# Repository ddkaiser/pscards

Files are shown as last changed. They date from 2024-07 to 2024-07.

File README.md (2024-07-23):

# pscards
Custom cards for restoring or repairing Korg PS-3x00 polyphonic synthesizers

## Overview

### Goal
Korg Polyphonic Synthesizers (PS-3100, PS-3200, PS-3300) are complex and expensive synthesizers, but as these instruments are now at least 45 years old, occasionally their original parts fail, and there is a need for recreated parts, in order to keep the instrument in operating condition.

This project is to create spare circuit boards to keep these old synthesizers operating.

### Sub-Projects
- [`KLM-69`](KLM-69) : KiCad project
	-	KLM - 69 "GATE" board
		-	PS-3100 has KLM-69E
		-	PS-3200 has KLMC-69F or KLM-69G  (are these identical, unknown revision?)
- [`KLM-64`](KLM-64) : KiCad project
	-	KLM - 64 "SIGNAL GENERATOR" board
		-	PS-3100 has KLM-64E
		-	PS-3200 has KLMC-064D  (are these identical, unknown revision?)
- [`card-extender`](card-extender) : KiCad project
	-	Diagnostic support board
		-	A pass-through board that extends a card outside the Korg synth chassis, to enable easier access while diagnosing and repairing
		-	Plugs-in to Korg synth backplane, and provides 2 44-pin card socket connections to host the Korg KLM board.
		-	Sockets can be: [Sullins EBM22DREH](https://www.sullinscorp.com/product/?pn=EBM22DREH), [EDAC 305-044-520-202](https://edac.net/series/305?search_part=305-044-520-202), [Vector R644](https://www.vectorelect.com/connector-card-edge.html) or similar card sockets.
		-	Provides test-points in Molex 0.156” (3.96mm) header format, using vertical headers, [Molex KK396 part #0026481240](https://www.molex.com/en-us/products/part-detail/26481240)
- [`klib`](klib) : “KiCad Libraries” folder
	-	KiCad shared libraries (symbols, footprints, images, drawing sheets, project templates, 3D models) to be used common across sub-projects
	-	Shared folder should be referenced in sub-projects as `${KIPRJMOD}/../klib/`

## Criteria

### Technical Requirements
Original boards are:
- single-sided:
  - top layer has silk-screen component labels but no traces or soldermask
  - bottom layer of board has copper traces and soldermask
- 1.6mm thickness PCB
- 1oz. copper plating
	
#### Dimensions
- Dimensioning of card assumes landscape orientation
- Height: 177mm  (including edge-connector).
- Width: 240mm
- Edge connector pads mirror card-edge traces, but there can be some variance in edge connector sizing & placing
	- Edge connectors can be between 87.5mm & 89mm in width and 10mm in height.
	- Edge connectors can be from 14mm to 15.5mm from outer (left/right) card edge.
	- Edge connectors can have a 32.5mm to 34mm gap between them.

### Design Requirements
- Circuit projects require KiCad 8.0+
- Schematics pages are A4-sized
- Dimensioning in millimeters (mm)

## Notes

### External Resources
- Korg PS-3100 Schematic PDF document was retrieved from: https://archive.org/details/synthmanual-korg-ps-3100-schematics/

### Original Work is by Korg
- All references to the word Korg, pcb names and numbers, (KLM*) or use of Korg component references or other design, are based on the original work by Korg.
- This work in this project is to repair and restore an original Korg synthesizer, based on its service documents and schematics.

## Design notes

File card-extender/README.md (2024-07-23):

# pscards/card-extender

## Overview
KiCad project for creating a extender card. The extender card is useful for working on a Korg PS-Series Polyphonic Synthesizer.

The card is a pass-through board that extends a card outside the Korg synth chassis, to enable easier access while diagnosing and repairing

The extender card plugs-in to Korg synth backplane, and provides 2 44-pin card socket connections to host the Korg KLM board.

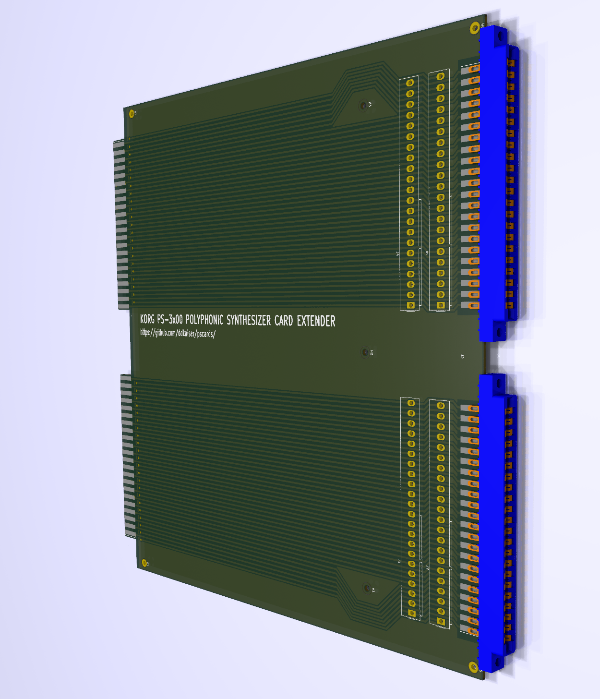
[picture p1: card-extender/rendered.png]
rendering of extender card for Korg PS-3x00 synths


## Parts

### Card-Edge Sockets
Sockets can be:

-	[Sullins EBM22DREH](https://www.sullinscorp.com/product/?pn=EBM22DREH)
-	[EDAC 305-044-520-202](https://edac.net/series/305?search_part=305-044-520-202)
-	[Vector R644](https://www.vectorelect.com/connector-card-edge.html)
-	or similar card sockets.

### Test Points
The card provides header pads for adding test points. 

The test points are:
-	Molex 0.156” (3.96mm) header format, using vertical headers
-	[Molex KK396 part #0026481240](https://www.molex.com/en-us/products/part-detail/26481240)

### Card Dimensions
- Dimensioning of card assumes landscape orientation
- Height: 228mm  (including edge-connector).
- Width: 240mm
- Edge connector pads mirror card-edge traces, but there can be some variance in edge connector sizing & placing
	- Edge connectors can be between 87.5mm & 89mm in width and 10mm in height.
	- Edge connectors can be from 14mm to 15.5mm from outer (left/right) card edge.
	- Edge connectors can have a 32.5mm to 34mm gap between them.

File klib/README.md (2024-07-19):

# pscards/klib
Directory for KiCad supporting libraries (symbols, footprints, images, sheet templates)

## Overview

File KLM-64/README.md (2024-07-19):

# pscards/KLM-64
KiCad project for creating restoration KLM-64 “SIGNAL GENERATOR” board for Korg PS-3x00 Polyphonic Synthesizers

## Overview

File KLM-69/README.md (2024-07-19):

# pscards/KLM-69
KiCad project for creating restoration KLM-69 “GATE” board for Korg PS-3x00 Polyphonic Synthesizers

## Overview

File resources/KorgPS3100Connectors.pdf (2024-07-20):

## Korg PS 3100

## Board Contacts

from front view | PS 3100
| KLM 64 | | KLM 64 | | KLM 69 | | KLM 69 | | KLM 69 | | KLM 69 | | KLM 62 | | KLM 63 | | KLM 76
Pin | Sig | | Sig | | Gate | | Gate | | Gate | | Gate | | Ctrl 1 | | Ctrl 2 | | Ctrl 3
44 | F (pitch) | 44 | B (pitch) | 44 | L Out | 44 | L Out | 44 | L Out | 44 | L Out | 44 | FC Mod R2 | 44 | MG1 FC Ctr | 44
43 | F# (pitch) | 43 | C (pitch) | 43 | U Out | 43 | U Out | 43 | U Out | 43 | U Out | 43 | FC Mod R1 | 43 | MG1 FC Ctr | 43
42 | G (pitch) | 42 | C# (pitch) | 42 | FC U | 42 | FC U | 42 | FC U | 42 | FC U | 42 | FC Mod 2 | 42 | MG1pNoise | 42
41 | G# (pitch) | 41 | D (pitch) | 41 | FC L | 41 | FC L | 41 | FC L | 41 | FC L | 41 | FC Mod 1 | 41 | MG1 wNoise | 41
40 | A (pitch) | 40 | D# (pitch) | 40 | Decay | 40 | Decay | 40 | Decay | 40 | Decay | 40 | FC Fine | 40 | | 40 | GND2
39 | A#(pitch) | 39 | E (pitch) | 39 | Ext.Attack | 39 | Ext.Attack | 39 | Ext.Attack | 39 | Ext.Attack | 39 | FC Coarse | 39 | | 39
38 | 4' | 38 | 4' | 38 | Attack | 38 | Attack | 38 | Attack | 38 | Attack | 38 | GND3 | 38 | GND3 | 38
37 | 8' | 37 | 8' | 37 | Expand | 37 | Expand | 37 | Expand | 37 | Expand | 37 | FC Bus Out | 37 | MG1 Tri | 37
36 | 16' | 36 | 16' | 36 | Sustain | 36 | Sustain | 36 | Sustain | 36 | Sustain | 36 | -15 V | 36 | MG1 Rect | 36
35 | | 35 | | 35 | Hold | 35 | Hold | 35 | Hold | 35 | Hold | 35 | GND2 | 35 | MG1 Saw dn | 35
34 | A#1 (Gate) | 34 | B1 (Gate) | 34 | E1 (sig) | 34 | E2 (sig) | 34 | E3 (sig) | 34 | E4 (sig) | 34 | L-Out (Mix) | 34 | MG1 Saw up | 34
33 | A#2 (Gate) | 33 | B2 (Gate) | 33 | D#1 (sig) | 33 | D#2 (sig) | 33 | D#3 (sig) | 33 | D#4 (sig) | 33 | GND2 | 33 | MG 1 ind | 33
32 | A#3 (Gate) | 32 | B3 (Gate) | 32 | D1 (sig) | 32 | D2 (sig) | 32 | D3 (sig) | 32 | D4 (sig) | 32 | L-In (Mix) | 32 | Ind 1 in | 32
31 | A#4 (Gate) | 31 | B4 (Gate) | 31 | C#1 (sig) | 31 | C#2 (sig) | 31 | C#3 (sig) | 31 | C#4 (sig) | 31 | GND2 | 31 | MG2 Sig Out | 31
30 | A1 (Gate) | 30 | C1 (Gate) | 30 | C1 (sig) | 30 | C2 (sig) | 30 | C3 (sig) | 30 | C4 (sig) | 30 | U-Out (Mix) | 30 | MG2 Sig In | 30
29 | A2 (Gate) | 29 | C2 (Gate) | 29 | B1 (sig) | 29 | B2 (sig) | 29 | B3 (sig) | 29 | B4 (sig) | 29 | GND2 | 29 | MG VCA Ctr. | 29
28 | A3 (Gate) | 28 | C3 (Gate) | 28 | A#1 (sig) | 28 | A#2 (sig) | 28 | A#3 (sig) | 28 | A#4 (sig) | 28 | U-In (Mix) | 28 | MG2 Ind | 28 | LMB 2
27 | A4 (Gate) | 27 | C4 (Gate) | 27 | A1 (sig) | 27 | A2 (sig) | 27 | A3 (sig) | 27 | A4 (sig) | 27 | GND2 | 27 | MG2 Out | 27 | LMA 2
26 | G#1 (Gate) | 26 | C#1 (Gate) | 26 | G#1 (sig) | 26 | G#2 (sig) | 26 | G#3 (sig) | 26 | G#4 (sig) | 26 | AM Sig Out | 26 | MG Freq. | 26 | Proc 2 out
25 | G#2 (Gate) | 25 | C#2 (Gate) | 25 | G1 (sig) | 25 | G2 (sig) | 25 | G3 (sig) | 25 | G4 (sig) | 25 | GND2 | 25 | | 25 | Proc 1 Out
24 | G#3 (Gate) | 24 | C#3 (Gate) | 24 | F#1 (sig) | 24 | F#2 (sig) | 24 | F#3 (sig) | 24 | F#4 (sig) | 24 | AM Sig in | 24 | | 24 | LMB 1
23 | G#4 (Gate) | 23 | C#4 (Gate) | 23 | F1 (sig) | 23 | F2 (sig) | 23 | F3 (sig) | 23 | F4 (sig) | 23 | AM Mod In | 23 | | 23 | LMA 1
22 | G1 (Gate) | 22 | D1 (Gate) | 22 | E1 (keyb) | 22 | E2 (keyb) | 22 | E3 (keyb) | 22 | E4 (keyb) | 22 | GND2 | 22 | GND2 | 22 | LM 1
21 | G2 (Gate) | 21 | D2 (Gate) | 21 | D#1 (keyb) | 21 | D#2 (keyb) | 21 | D#3 (keyb) | 21 | D#4 (keyb) | 21 | GND2 | 21 | | 21 | LM 2
20 | G3 (Gate) | 20 | D3 (Gate) | 20 | D1 (keyb) | 20 | D2 (keyb) | 20 | D3 (keyb) | 20 | D4 (keyb) | 20 | Res Out 2 | 20 | | 20 | VP 2 In
19 | G4 (Gate) | 19 | D4 (Gate) | 19 | C#1 (keyb) | 19 | C#2 (keyb) | 19 | C#3 (keyb) | 19 | C#4 (keyb) | 19 | GND2 | 19 | P50% Select | 19 | VP 1 In
18 | F#1 (Gate) | 18 | D#1 (Gate) | 18 | C1 (keyb) | 18 | C2 (keyb) | 18 | C3 (keyb) | 18 | C4 (keyb) | 18 | Res Out 1 | 18 | P30% Select | 18 | GEG Attack
17 | F#2 (Gate) | 17 | D#2 (Gate) | 17 | B1 (keyb) | 17 | B2 (keyb) | 17 | B3 (keyb) | 17 | B4 (keyb) | 17 | GND2 | 17 | P10% Select | 17 | GEG Out 0V
16 | F#3 (Gate) | 16 | D#3 (Gate) | 16 | A#1 (keyb) | 16 | A#2 (keyb) | 16 | A#3 (keyb) | 16 | A#4 (keyb) | 16 | Res In | 16 | PWM Select | 16 GEG Out +5V
15 | F#4 (Gate) | 15 | D#4 (Gate) | 15 | A1 (keyb) | 15 | A2 (keyb) | 15 | A3 (keyb) | 15 | A4 (keyb) | 15 | 15 | PWM In | 15GEG Auto Out
14 | F1 (Gate) | 14 | E1 (Gate) | 14 | G#1 (keyb) | 14 | G#2 (keyb) | 14 | G#3 (keyb) | 14 | G#4 (keyb) | 14 | 14 | Tri Select | 14 GEG Out -5V
13 | F2 (Gate) | 13 | E2 (Gate) | 13 | G1 (keyb) | 13 | G2 (keyb) | 13 | G3 (keyb) | 13 | G4 (keyb) | 13 | 13 | WFD (Sig) | 13 GEG Release
12 | F3 (Gate) | 12 | E3 (Gate) | 12 | F#1 (keyb) | 12 | F#2 (keyb) | 12 | F#3 (keyb) | 12 | F#4 (keyb) | 12 | | 12 | WFR (Sig) | 12 | GEG Auto In
11 | F4 (Gate) | 11 | E4 (Gate) | 11 | F1 (keyb) | 11 | F2 (keyb) | 11 | F3 (keyb) | 11 | F4 (keyb) | 11 | Peak Cont 3 | 11 | Saw Select | 11 | GEG Trig In
10 | | 10 | | 10 | nc / G2 (?) | 10 | nc / G2 (?) | 10 | nc / G2 (?) | 10 | nc / G2 (?) | 10 | Peak Cont 2 | 10 | FC L | 10 | GEG Delay
9 | | 9 | | 9 | (?) | 9 | (?) | 9 | (?) | 9 | (?) | 9 | Peak Cont 1 | 9 | FC U | 9 | Sync Ind
8 | | 8 | | 8 | Key Trig | 8 | Key Trig | 8 | Key Trig | 8 | Key Trig | 8 | Res Mod 2 | 8 | Balance | 8 | Sync In
7 | WFR | 7 | WFR | 7 | +10V | 7 | +10V | 7 | +10V | 7 | +10V | 7 | Res Mod 1 | 7 | VCF Mod 2 | 7 | S/H FC In
6 | WFD | 6 | WFD | 6 | Release | 6 | Release | 6 | Release | 6 | Release | 6 REL GND On | 6 | VCF Mod 1 | 6 | S/H In
5 | 5 | 5 | Peak | 5 | Peak | 5 | Peak | 5 | Peak | 5Gate REL Term | 5 | VCF FC | 5 | S/H Out
4 | | 4 | | 4 | GND3 | 4 | GND3 | 4 | GND3 | 4 | GND3 | 4 | HD GND On | 4 | FC Bias | 4 | Sync Out
3 | -15V | 3 | -15V | 3 | -15V | 3 | -15V | 3 | -15V | 3 | -15V | 3 | -15V | 3 | -15V | 3 | -15V
2 | GND | 2 | GND | 2 | GND | 2 | GND | 2 | GND | 2 | GND | 2 | GND | 2 | GND | 2 | GND
1 | +15V | 1 | +15V | 1 | +15V | 1 | +15V | 1 | +15V | 1 | +15V | 1 | +15V | 1 | +15V | 1 | +15V

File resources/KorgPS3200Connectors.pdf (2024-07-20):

## Korg PS 3200

## Board Contacts

from front view | PS 3200
| KLM 64 | | KLM 64 | | KLM 64 | | KLM 64 | | KLM 69 | | KLM 69 | | KLM 69 | | KLM 69 | | KLM 147 | | KLM 148 | | KLM 149 | | KLM 146 | | KLM 150 | | KLM 76
Pin | SG | | SG | | SG | | SG | | Gate | | Gate | | Gate | | Gate | | Freq.&Wave | | Filter & Rel. | | EQ AM BMix | | MG1, S/H, MB | | Ctrl 3 | | PHONE AMP
| | | | | | | | | | | | | | | | | Control | | Control | | | | MVCA | | MG2 AA, EBC | | VCA, GEG VP
44 | F (pitch) | 44 | B (pitch) | 44 | F (pitch) | 44 | B (pitch) | 44 | L Out | 44 | L Out | 44 | L Out | 44 | L Out | 44SG1 Temp. Bu | 44 | ? | 44 | P1 #18 | 44 | ? | 44 | SG2 16' | 44 | ?
43 | F# (pitch) | 43 | C (pitch) | 43 | F# (pitch) | 43 | C (pitch) | 43 | U Out | 43 | U Out | 43 | U Out | 43 | U Out | 43 | REV 1 | 43Ext Cutoff Freq | 43 | P0 #18 | 43 | ? | 43 | SG2 8' | 43 | ?
42 | G (pitch) | 42 | C# (pitch) | 42 | G (pitch) | 42 | C# (pitch) | 42 | FC U | 42 | FC U | 42 | FC U | 42 | FC U | 42 | GND 3 | 42 | MG1 | 42 | VS #18 | 42 | GND 3 | 42 | SG2 4' | 42 | ?
41 | G# (pitch) | 41 | D (pitch) | 41 | G# (pitch) | 41 | D (pitch) | 41 | FC L | 41 | FC L | 41 | FC L | 41 | FC L | 41 | MG1 | 41 | FC L | 41 | P1 #19 | 41 | MG1 Out | 41 | SG1 16' | 41 | ?
40 | A (pitch) | 40 | D# (pitch) | 40 | A (pitch) | 40 | D# (pitch) | 40 | Decay | 40 | Decay | 40 | Decay | 40 | Decay | 40SG2 Temp. Bu | 40 | FC U | 40 | P0 #19 | 40 MG1 Ext Freq | 40 | SG1 8' | 40 | GND2
39 | A#(pitch) | 39 | E (pitch) | 39 | A#(pitch) | 39 | E (pitch) | 39 | Ext.Attack | 39 | Ext.Attack | 39 | Ext.Attack | 39 | Ext.Attack | 39 SG2 Ext Mod | 39 | P1 #11 | 39 | VS #19 | 39 | ? | 39 | SG1 4' | 39 | ?
38 | 4' | 38 | 4' | 38 | 4' | 38 | 4' | 38 | Attack | 38 | Attack | 38 | Attack | 38 | Attack | 38 | MG 1 Check | 38 | P0 #11 | 38 | P1 #20 | 38 | ? | 38 | GND 3 | 38 | ?
37 | 8' | 37 | 8' | 37 | 8' | 37 | 8' | 37 | Expand | 37 | Expand | 37 | Expand | 37 | Expand | 37 | Tot Ext Mod | 37 | VS #11 | 37 | P0 #20 | 37 | ? | 37 | P1 #02 | 37 | ?
36 | 16' | 36 | 16' | 36 | 16' | 36 | 16' | 36 | Sustain | 36 | Sustain | 36 | Sustain | 36 | Sustain | 36 | Tot Freq | 36 | VS #13 | 36 | VS #20 | 36 | ? | 36SG1 Scale Ou | 36 | ?
35 | | 35 | | 35 | | 35 | | 35 | Hold | 35 | Hold | 35 | Hold | 35 | Hold | 35 | P1 #05 | 35 | P1 #13 | 35 | P1 #21 | 35 | ? | 35 | P0 #02 | 35 | ?
34 | A#1 (Gate) | 34 | B1 (Gate) | 34 | A#1 (Gate) | 34 | B1 (Gate) | 34 | E1 (sig) | 34 | E2 (sig) | 34 | E3 (sig) | 34 | E4 (sig) | 34 | P0 #08 | 34 | P0 #13 | 34 | P0 #21 | 34 | ? | 34 | VS #02 | 34 | ?
33 | A#2 (Gate) | 33 | B2 (Gate) | 33 | A#2 (Gate) | 33 | B2 (Gate) | 33 | D#1 (sig) | 33 | D#2 (sig) | 33 | D#3 (sig) | 33 | D#4 (sig) | 33 | ? | 33 | P1 #09 | 33 | VS #21 | 33 | P1 #28 | 33 | CVS #04 | 33 | ?
32 | A#3 (Gate) | 32 | B3 (Gate) | 32 | A#3 (Gate) | 32 | B3 (Gate) | 32 | D1 (sig) | 32 | D2 (sig) | 32 | D3 (sig) | 32 | D4 (sig) | 32 | VS #08 | 32 | P0 #09 | 32 | P1 #22 | 32 | P0 #28 | 32 | P1#04 | 32 | ?
31 | A#4 (Gate) | 31 | B4 (Gate) | 31 | A#4 (Gate) | 31 | B4 (Gate) | 31 | C#1 (sig) | 31 | C#2 (sig) | 31 | C#3 (sig) | 31 | C#4 (sig) | 31 | P1 #08 | 31 | VS #09 | 31 | P0 #22 | 31 | VS #28 | 31SG2 Scale Ou | 31 | ?
30 | A1 (Gate) | 30 | C1 (Gate) | 30 | A1 (Gate) | 30 | C1 (Gate) | 30 | C1 (sig) | 30 | C2 (sig) | 30 | C3 (sig) | 30 | C4 (sig) | 30 | P0 #05 | 30 | VS #12 | 30 | VS #22 | 30 | VS “27 | 30 | P0 #04 | 30 | ?
29 | A2 (Gate) | 29 | C2 (Gate) | 29 | A2 (Gate) | 29 | C2 (Gate) | 29 | B1 (sig) | 29 | B2 (sig) | 29 | B3 (sig) | 29 | B4 (sig) | 29 | VS #05 | 29 | P1 #12 | 29 | P1 #23 | 29 | P1 #27 | 29 | ? | 29 | ?
28 | A3 (Gate) | 28 | C3 (Gate) | 28 | A3 (Gate) | 28 | C3 (Gate) | 28 | A#1 (sig) | 28 | A#2 (sig) | 28 | A#3 (sig) | 28 | A#4 (sig) | 28 | REV 2 | 28 | Expand Cont | 28 | P0 #23 | 28 | P0 #27 | 28 | ? | 28 | LMB 2
27 | A4 (Gate) | 27 | C4 (Gate) | 27 | A4 (Gate) | 27 | C4 (Gate) | 27 | A1 (sig) | 27 | A2 (sig) | 27 | A3 (sig) | 27 | A4 (sig) | 27 | MG 3 Out | 27 | P0 #12 | 27 | VS #23 | 27 | P1 #29 | 27 | EC IN 2 | 27 | LMA 2
26 | G#1 (Gate) | 26 | C#1 (Gate) | 26 | G#1 (Gate) | 26 | C#1 (Gate) | 26 | G#1 (sig) | 26 | G#2 (sig) | 26 | G#3 (sig) | 26 | G#4 (sig) | 26 | P1 #07 | 26 | P1 #10 | 26 | P1 #24 | 26 | P0 #29 | 26 | GND | 26 | Proc 2 out
25 | G#2 (Gate) | 25 | C#2 (Gate) | 25 | G#2 (Gate) | 25 | C#2 (Gate) | 25 | G1 (sig) | 25 | G2 (sig) | 25 | G3 (sig) | 25 | G4 (sig) | 25 | P0 #06 | 25 | PEAK Cont | 25 | P0 #24 | 25 | VS #29 | 25 | EC IN 1 | 25 | Proc 1 Out
24 | G#3 (Gate) | 24 | C#3 (Gate) | 24 | G#3 (Gate) | 24 | C#3 (Gate) | 24 | F#1 (sig) | 24 | F#2 (sig) | 24 | F#3 (sig) | 24 | F#4 (sig) | 24 | ? | 24 | P0 #10 | 24 | VS #24 | 24 | ? | 24 | GND | 24 | LMB 1
23 | G#4 (Gate) | 23 | C#4 (Gate) | 23 | G#4 (Gate) | 23 | C#4 (Gate) | 23 | F1 (sig) | 23 | F2 (sig) | 23 | F3 (sig) | 23 | F4 (sig) | 23 | P/C (?) | 23 | P/C (?) | 23 | P/C (?) | 23 | P/C (?) | 23 | ? | 23 | LMA 1
22 | G1 (Gate) | 22 | D1 (Gate) | 22 | G1 (Gate) | 22 | D1 (Gate) | 22 | E1 (keyb) | 22 | E2 (keyb) | 22 | E3 (keyb) | 22 | E4 (keyb) | 22 | VS #06 | 22 | VS #10 | 22 | EQ out | 22 | VS #30 | 22 | GND 2 | 22 | LM 1
21 | G2 (Gate) | 21 | D2 (Gate) | 21 | G2 (Gate) | 21 | D2 (Gate) | 21 | D#1 (keyb) | 21 | D#2 (keyb) | 21 | D#3 (keyb) | 21 | D#4 (keyb) | 21 | P1 #06 | 21 | VS #16 | 21 | Direct Out | 21 | P1 #30 | 21 | EC Out | 21 | LM 2
20 | G3 (Gate) | 20 | D3 (Gate) | 20 | G3 (Gate) | 20 | D3 (Gate) | 20 | D1 (keyb) | 20 | D2 (keyb) | 20 | D3 (keyb) | 20 | D4 (keyb) | 20 | P0 #07 | 20 | P1 #16 | 20 | AM Check | 20 | P0 #30 | 20 | P1 #31 | 20 | VP 2 In
19 | G4 (Gate) | 19 | D4 (Gate) | 19 | G4 (Gate) | 19 | D4 (Gate) | 19 | C#1 (keyb) | 19 | C#2 (keyb) | 19 | C#3 (keyb) | 19 | C#4 (keyb) | 19 | VS #07 | 19 | Sustain Cont | 19 | Mix Out | 19 | GND 2 | 19 | P0 #31 | 19 | VP 1 In
18 | F#1 (Gate) | 18 | D#1 (Gate) | 18 | F#1 (Gate) | 18 | D#1 (Gate) | 18 | C1 (keyb) | 18 | C2 (keyb) | 18 | C3 (keyb) | 18 | C4 (keyb) | 18 | SG1 PWM | 18 | P0 #16 | 18 | GND 3 | 18 | ? | 18 | VS #31 | 18 | GEG Attack
17 | F#2 (Gate) | 17 | D#2 (Gate) | 17 | F#2 (Gate) | 17 | D#2 (Gate) | 17 | B1 (keyb) | 17 | B2 (keyb) | 17 | B3 (keyb) | 17 | B4 (keyb) | 17 | SG 1 WFR | 17 | Rel GND On | 17 | MG 1 (?) | 17 | SH Ind | 17 | VS #32 | 17 | GEG Out 0V
16 | F#3 (Gate) | 16 | D#3 (Gate) | 16 | F#3 (Gate) | 16 | D#3 (Gate) | 16 | A#1 (keyb) | 16 | A#2 (keyb) | 16 | A#3 (keyb) | 16 | A#4 (keyb) | 16 | SG 1 WFD | 16 | Rel Control | 16 | GND 2 | 16 | S/H Trig Out | 16 | P1 #32 | 16GEG Out +5V
15 | F#4 (Gate) | 15 | D#4 (Gate) | 15 | F#4 (Gate) | 15 | D#4 (Gate) | 15 | A1 (keyb) | 15 | A2 (keyb) | 15 | A3 (keyb) | 15 | A4 (keyb) | 15 | ? | 15 | VS #17 | 15 | AM Sig Out | 15 | ? | 15 | P0 #32 | 15GEG Auto Ou
14 | F1 (Gate) | 14 | E1 (Gate) | 14 | F1 (Gate) | 14 | E1 (Gate) | 14 | G#1 (keyb) | 14 | G#2 (keyb) | 14 | G#3 (keyb) | 14 | G#4 (keyb) | 14 | P1 #03 | 14 | P1 #17 | 14 | GND 2 | 14 | MG1 Ind | 14 | ADD IN 1 | 14 GEG Out -5V
13 | F2 (Gate) | 13 | E2 (Gate) | 13 | F2 (Gate) | 13 | E2 (Gate) | 13 | G1 (keyb) | 13 | G2 (keyb) | 13 | G3 (keyb) | 13 | G4 (keyb) | 13 | P0 #01 | 13 | P0 #17 | 13 | GND 2 | 13 | ? | 13 | ADD IN 2 | 13 GEG Release
12 | F3 (Gate) | 12 | E3 (Gate) | 12 | F3 (Gate) | 12 | E3 (Gate) | 12 | F#1 (keyb) | 12 | F#2 (keyb) | 12 | F#3 (keyb) | 12 | F#4 (keyb) | 12 | VS #01 | 12 | P1 #15 | 12 | Bmix Lo In | 12 | ? | 12 | INV Out | 12 | GEG Auto In
11 | F4 (Gate) | 11 | E4 (Gate) | 11 | F4 (Gate) | 11 | E4 (Gate) | 11 | F1 (keyb) | 11 | F2 (keyb) | 11 | F3 (keyb) | 11 | F4 (keyb) | 11 | P1 #01 | 11 | Decay Cont | 11 | GND | 11 | ? | 11 | ADD OUT | 11 | GEG Trig In
10 | | 10 | | 10 | | 10 | | 10 | nc / G2 (?) | 10 | nc / G2 (?) | 10 | nc / G2 (?) | 10 | nc / G2 (?) | 10 | P0 #03 | 10 | P0 #15 | 10 | BMix Up In | 10 | ? | 10 | PV Out | 10 | GEG Delay
9 | | 9 | | 9 | | 9 | | 9 | (?) | 9 | (?) | 9 | (?) | 9 | (?) | 9 | VS #03 | 9 | VS #15 | 9 | P1 #11 (?) | 9 | SH IN | 9 | MVCA Out | 9 | Sync Ind
8 | | 8 | | 8 | | 8 | | 8 | Key Trig | 8 | Key Trig | 8 | Key Trig | 8 | Key Trig | 8 | SG 2 PWM | 8 | VS #14 | 8 | P0 #11 (?) | 8 | S/H Trig In | 8 | MVCA IN | 8 | Sync In
7 | WFR | 7 | WFR | 7 | WFR | 7 | WFR | 7 | +10V | 7 | +10V | 7 | +10V | 7 | +10V | 7 | SG 2 WFR | 7 | P1 #14 | 7 | VS #11 (?) | 7 | SH Out | 7 | MVCA Ctrl | 7 | S/H FC In
6 | WFD | 6 | WFD | 6 | WFD | 6 | WFD | 6 | Release | 6 | Release | 6 | Release | 6 | Release | 6 | SG 2 WFD | 6 | Attack Cont | 6 | P1 #25 | 6 | Sync OUT | 6 | MG2 FC | 6 | S/H In
5 | | 5 | | 5 | | 5 | | 5 | Peak | 5 | Peak | 5 | Peak | 5 | Peak | 5 | ? | 5 | P0 #14 | 5 | P0 #25 | 5 | ? | 5 | MG2 Out | 5 | S/H Out
4 | 4 | 4 | 4 | 4 | GND3 | 4 | GND3 | 4 | GND3 | 4 | GND3 | 4 | ? | 4 | FC BIAS | 4 | VS #25 | 4MG1 Gain Ou | 4 | MG2 Ind | 4 | Sync Out
3 | -15V | 3 | -15V | 3 | -15V | 3 | -15V | 3 | -15V | 3 | -15V | 3 | -15V | 3 | -15V | 3 | -15V | 3 | -15V | 3 | -15V | 3 | -15V | 3 | -15V | 3 | -15V
2 | GND | 2 | GND | 2 | GND | 2 | GND | 2 | GND | 2 | GND | 2 | GND | 2 | GND | 2 | GND | 2 | GND | 2 | GND | 2 | GND | 2 | GND | 2 | GND
1 | +15V | 1 | +15V | 1 | +15V | 1 | +15V | 1 | +15V | 1 | +15V | 1 | +15V | 1 | +15V | 1 | +15V | 1 | +15V | 1 | +15V | 1 | +15V | 1 | +15V | 1 | +15V
GND2 nicht lesbar | AM MOD nicht lesbar

Programmer | Power | Programmer Selector | Abbreviaions | Knob Numbers
| KLM 151 | | KLM 152 | | KLM 153 | | KLM 65 | | KLM 154
| A/D DIS | | RAM AC | | Hold | | | | | A/D | Analog Digital Converter | #01 | SG1 Waveform
| DIS | | CG PC | | DOS D/A | | | | | AA | Adding Amp | #02 | SG1 Scale
44 | IA 5 | 44 | IA 5 | 44 | IA 5 | 44 | ? | 44 | ? | AC | Address Counter | #03 | SG2 Waveform
43 | IA 4 | 43 | IA 4 | 43 | IA 4 | 43 | ? | 43 | ? | AM | Amplitude Modulator | #04 | SG2 Scale
42 | IA 3 | 42 | IA 3 | 42 | IA 3 | 42 | ? | 42 | ? | BMix | Filter Balance Mixer | #05 | SG2 Frequency
41 | IA 2 | 41 | IA 2 | 41 | IA 2 | 41 | ? | 41 | ? | CG | Clock Generator | #06 | Total PWM Speed
40 | IA 1 | 40 | IA 1 | 40 | IA 1 | 40 | ? | 40 | ? | D/A | Digital Analog Converter | #07 | Total PWM Intensity
39 | ? | 39 | ? | 39 | ? | 39 | ? | 39 | ? | DIS | Data Input Scanner | #08 | Total Frequ Mod Intensity
38 | PI #32 | 38 | ? | 38 | P0 #32 | 38 | ? | 38 | ? | DOS | Data Output Scanner | #09 | DLPF Cutoff Freqency
37 | PI #31 | 37 | ? | 37 | P0 #31 | 37 | ? | 37 | ? | EBC | Ensemble Balance Control | #10 | DLPF Peak
36 | PI #30 | 36 | ? | 36 | P0 #30 | 36 | ? | 36 | PB 16 | EQ | Equalizer | #11 | DLPF KBD Filt Balance
35 | PI #29 | 35 | ? | 35 | P0 #29 | 35 | ? | 35 | PB 15 | GEG | General Envelope Generator | #12 | DLPF Expand
34 | PI #28 | 34 | ? | 34 | P0 #28 | 34 | ? | 34 | PB 14 | MB | Modulation Balance | #13 | DLPF Mod Intensity
33 | PI #27 | 33 | ? | 33 | P0 #27 | 33 | ? | 33 | PB 13 | MG | Modulation Generator | #14 | EM Attack Time
32 | PI #26 | 32 | ? | 32 | P0 #26 | 32 | ? | 32 | PB 12 | MVCA | Modulation VCA | #15 | EM Decay Time
31 | PI #25 | 31 | ? | 31 | P0 #25 | 31 | ? | 31 | PB 11 | PC | Programmer Control | #16 | EM Sustain Level
30 | PI #24 | 30 | ? | 30 | P0 #24 | 30 | ? | 30 | PB 10 | S/H | Sample & Hold | #17 | EM Release Time
29 | PI #23 | 29 | ? | 29 | P0 #23 | 29 | ? | 29 | PB 09 | SG | Signal Generator | #18 | EQ 8 kHz
28 | PI #22 | 28 | AD Start | 28 | P0 #22 | 28 | ? | 28 | PB 08 | VP | Voltage Processor | #19 | EQ 4 kHz
27 | PI #21 | 27 | Hold | 27 | P0 #21 | 27 | ? | 27 | PB 07 | PV | Preset Volume | #20 | EQ 2 kHz
26 | PI #20 | 26 | Data Latch | 26 | P0 #20 | 26 | ? | 26 | PB 06 | | | #21 | EQ 1kHz
25 | PI #19 | 25 | ? | 25 | P0 #19 | 25 | ? | 25 | PB 05 | | | #22 | EQ 500 Hz
24 | PI #18 | 24 | ? | 24 | P0 #18 | 24 | ? | 24 | PB 04 | | | #23 | EQ 250 Hz
23 | PI #17 | 23 | ? | 23 | P0 #17 | 23 | ? | 23 | PB 03 | | | #24 | EQ 125 Hz
| | | | | | | | | | | | #25 | Amplitude Modulation
22 | PI #16 | 22 | ? | 22 | P0 #16 | 22 | ? | 22 | PB 02 | | | #26 | KBD Vol Balance
21 | PI #15 | 21 | ? | 21 | P0 #15 | 21 | ? | 21 | PB 01 | | | #27 | MG1 Waveform
20 | PI #14 | 20 | ? | 20 | P0 #14 | 20 | ? | 20 | ? | | | #28 | MG1 Frequency
19 | PI #13 | 19 | ? | 19 | P0 #13 | 19 | ? | 19 | ? | | | #29 | S/H Clock
18 | PI #12 | 18 | ? | 18 | P0 #12 | 18 | ? | 18 | ? | | | #30 | Modulation Balance
17 | PI #11 | 17 | ? | 17 | P0 #11 | 17 | ? | 17 | ? | | | #31 | Ensemble
16 | PI #10 | 16 | ? | 16 | P0 #10 | 16 | ? | 16 | ? | | | #32 | Preset Volume
15 | PI #09 | 15 | ? | 15 | P0 #09 | 15 | ? | 15 | GNC
14 | PI #08 | 14 | ? | 14 | P0 #08 | 14 | ? | 14 | +15V
13 | PI #07 | 13 | ? | 13 | P0 #07 | 13 | ? | 13 | ?
12 | PI #06 | 12 | ? | 12 | P0 #06 | 12 | ? | 12 | WIRTE
11 | PI #05 | 11 | PS 2 | 11 | P0 #05 | 11 | TRAFO 4 | 11 | PA 4
10 | PI #04 | 10 | WRITE | 10 | P0 #04 | 10 | TRAFO 3 | 10 | PA 3
9 | PI #03 | 9 | CANCEL | 9 | P0 #03 | 9 | TRAFO 2 | 9 | PA 2
8 | PI #02 | 8 | RS 1 | 8 | P0 #02 | 8 | TRAFO 1 | 8 | PA 1
7 | PI #01 | 7 | ? | 7 | P0 #01 | 7 | VD +15V | 7 | PS 2
6 | PI #00 | 6 | ? | 6 | DATA Latch | 6 | +5V (?) | 6 | PS 1
5 | ? | 5 | ? | 5DA OUT CHCK | 5 | +10V | 5 | CANCEL 1
4 | ? | 4 | ? | 4 | ? | 4 | GND | 4 | CANCEL 2
3 | ? | 3 | -15V | 3 | -15V | 3 | -15V | 3 | P/C
2 | ? | 2 | GND | 2 | GND | 2 | GND | 2 | ?
1 | ? | 1 | +15V | 1 | +15V | 1 | +15V | 1 | ?

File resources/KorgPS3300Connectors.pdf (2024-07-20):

## Korg PS 3300

## Board Contacts

from front view | PS 3301 - 1 | PS 3301 - 2
| KLM 64 | | KLM 64 | | KLM 69 | | KLM 69 | | KLM 69 | | KLM 69 | | KLM 62 | | KLM 63 | | KLM 64 | | KLM 64 | | KLM 69 | | KLM 69 | | KLM 69
Pin | Sig | | Sig | | Gate | | Gate | | Gate | | Gate | | Ctrl 1 | | Ctrl 2 | | Sig | | Sig | | Gate | | Gate | | Gate
44 | F (pitch) | 44 | B (pitch) | 44 | L Out | 44 | L Out | 44 | L Out | 44 | L Out | 44 | FC Mod R2 | 44 | MG1 FC Ctr | 44 | F (pitch) | 44 | B (pitch) | 44 | L Out | 44 | L Out | 44 | L Out | 44
43 | F# (pitch) | 43 | C (pitch) | 43 | U Out | 43 | U Out | 43 | U Out | 43 | U Out | 43 | FC Mod R1 | 43 | MG1 FC Ctr | 43 | F# (pitch) | 43 | C (pitch) | 43 | U Out | 43 | U Out | 43 | U Out | 43
42 | G (pitch) | 42 | C# (pitch) | 42 | FC U | 42 | FC U | 42 | FC U | 42 | FC U | 42 | FC Mod 2 | 42 | MG1pNoise | 42 | G (pitch) | 42 | C# (pitch) | 42 | FC U | 42 | FC U | 42 | FC U | 42
41 | G# (pitch) | 41 | D (pitch) | 41 | FC L | 41 | FC L | 41 | FC L | 41 | FC L | 41 | FC Mod 1 | 41 | MG1 wNoise | 41 | G# (pitch) | 41 | D (pitch) | 41 | FC L | 41 | FC L | 41 | FC L | 41
40 | A (pitch) | 40 | D# (pitch) | 40 | Decay | 40 | Decay | 40 | Decay | 40 | Decay | 40 | FC Fine | 40 | | 40 | A (pitch) | 40 | D# (pitch) | 40 | Decay | 40 | Decay | 40 | Decay | 40
39 | A#(pitch) | 39 | E (pitch) | 39 | Ext.Attack | 39 | Ext.Attack | 39 | Ext.Attack | 39 | Ext.Attack | 39 | FC Coarse | 39 | | 39 | A#(pitch) | 39 | E (pitch) | 39 | Ext.Attack | 39 | Ext.Attack | 39 | Ext.Attack | 39
38 | 4' | 38 | 4' | 38 | Attack | 38 | Attack | 38 | Attack | 38 | Attack | 38 | GND3 | 38 | GND3 | 38 | 4' | 38 | 4' | 38 | Attack | 38 | Attack | 38 | Attack | 38
37 | 8' | 37 | 8' | 37 | Expand | 37 | Expand | 37 | Expand | 37 | Expand | 37 | FC Bus Out | 37 | MG1 Tri | 37 | 8' | 37 | 8' | 37 | Expand | 37 | Expand | 37 | Expand | 37
36 | 16' | 36 | 16' | 36 | Sustain | 36 | Sustain | 36 | Sustain | 36 | Sustain | 36 | -15 V | 36 | MG1 Rect | 36 | 16' | 36 | 16' | 36 | Sustain | 36 | Sustain | 36 | Sustain | 36
35 | | 35 | | 35 | Hold | 35 | Hold | 35 | Hold | 35 | Hold | 35 | GND2 | 35 | MG1 Saw dn | 35 | | 35 | | 35 | Hold | 35 | Hold | 35 | Hold | 35
34 | A#1 (Gate) | 34 | B1 (Gate) | 34 | E1 (sig) | 34 | E2 (sig) | 34 | E3 (sig) | 34 | E4 (sig) | 34 | L-Out (Mix) | 34 | MG1 Saw up | 34 | A#1 (Gate) | 34 | B1 (Gate) | 34 | E1 (sig) | 34 | E2 (sig) | 34 | E3 (sig) | 34
33 | A#2 (Gate) | 33 | B2 (Gate) | 33 | D#1 (sig) | 33 | D#2 (sig) | 33 | D#3 (sig) | 33 | D#4 (sig) | 33 | GND2 | 33 | MG 1 ind | 33 | A#2 (Gate) | 33 | B2 (Gate) | 33 | D#1 (sig) | 33 | D#2 (sig) | 33 | D#3 (sig) | 33
32 | A#3 (Gate) | 32 | B3 (Gate) | 32 | D1 (sig) | 32 | D2 (sig) | 32 | D3 (sig) | 32 | D4 (sig) | 32 | L-In (Mix) | 32 | Ind 1 in | 32 | A#3 (Gate) | 32 | B3 (Gate) | 32 | D1 (sig) | 32 | D2 (sig) | 32 | D3 (sig) | 32
31 | A#4 (Gate) | 31 | B4 (Gate) | 31 | C#1 (sig) | 31 | C#2 (sig) | 31 | C#3 (sig) | 31 | C#4 (sig) | 31 | GND2 | 31 | MG2 Sig Out | 31 | A#4 (Gate) | 31 | B4 (Gate) | 31 | C#1 (sig) | 31 | C#2 (sig) | 31 | C#3 (sig) | 31
30 | A1 (Gate) | 30 | C1 (Gate) | 30 | C1 (sig) | 30 | C2 (sig) | 30 | C3 (sig) | 30 | C4 (sig) | 30 | U-Out (Mix) | 30 | MG2 Sig In | 30 | A1 (Gate) | 30 | C1 (Gate) | 30 | C1 (sig) | 30 | C2 (sig) | 30 | C3 (sig) | 30
29 | A2 (Gate) | 29 | C2 (Gate) | 29 | B1 (sig) | 29 | B2 (sig) | 29 | B3 (sig) | 29 | B4 (sig) | 29 | GND2 | 29 | MG VCA Ctr. | 29 | A2 (Gate) | 29 | C2 (Gate) | 29 | B1 (sig) | 29 | B2 (sig) | 29 | B3 (sig) | 29
28 | A3 (Gate) | 28 | C3 (Gate) | 28 | A#1 (sig) | 28 | A#2 (sig) | 28 | A#3 (sig) | 28 | A#4 (sig) | 28 | U-In (Mix) | 28 | MG2 Ind | 28 | A3 (Gate) | 28 | C3 (Gate) | 28 | A#1 (sig) | 28 | A#2 (sig) | 28 | A#3 (sig) | 28
27 | A4 (Gate) | 27 | C4 (Gate) | 27 | A1 (sig) | 27 | A2 (sig) | 27 | A3 (sig) | 27 | A4 (sig) | 27 | GND2 | 27 | MG2 Out | 27 | A4 (Gate) | 27 | C4 (Gate) | 27 | A1 (sig) | 27 | A2 (sig) | 27 | A3 (sig) | 27
26 | G#1 (Gate) | 26 | C#1 (Gate) | 26 | G#1 (sig) | 26 | G#2 (sig) | 26 | G#3 (sig) | 26 | G#4 (sig) | 26 | AM Sig Out | 26 | MG Freq. | 26 | G#1 (Gate) | 26 | C#1 (Gate) | 26 | G#1 (sig) | 26 | G#2 (sig) | 26 | G#3 (sig) | 26
25 | G#2 (Gate) | 25 | C#2 (Gate) | 25 | G1 (sig) | 25 | G2 (sig) | 25 | G3 (sig) | 25 | G4 (sig) | 25 | GND2 | 25 | | 25 | G#2 (Gate) | 25 | C#2 (Gate) | 25 | G1 (sig) | 25 | G2 (sig) | 25 | G3 (sig) | 25
24 | G#3 (Gate) | 24 | C#3 (Gate) | 24 | F#1 (sig) | 24 | F#2 (sig) | 24 | F#3 (sig) | 24 | F#4 (sig) | 24 | AM Sig in | 24 | | 24 | G#3 (Gate) | 24 | C#3 (Gate) | 24 | F#1 (sig) | 24 | F#2 (sig) | 24 | F#3 (sig) | 24
23 | G#4 (Gate) | 23 | C#4 (Gate) | 23 | F1 (sig) | 23 | F2 (sig) | 23 | F3 (sig) | 23 | F4 (sig) | 23 | AM Mod In | 23 | | 23 | G#4 (Gate) | 23 | C#4 (Gate) | 23 | F1 (sig) | 23 | F2 (sig) | 23 | F3 (sig) | 23
22 | G1 (Gate) | 22 | D1 (Gate) | 22 | E1 (keyb) | 22 | E2 (keyb) | 22 | E3 (keyb) | 22 | E4 (keyb) | 22 | GND2 | 22 | GND2 | 22 | G1 (Gate) | 22 | D1 (Gate) | 22 | E1 (keyb) | 22 | E2 (keyb) | 22 | E3 (keyb) | 22
21 | G2 (Gate) | 21 | D2 (Gate) | 21 | D#1 (keyb) | 21 | D#2 (keyb) | 21 | D#3 (keyb) | 21 | D#4 (keyb) | 21 | GND2 | 21 | | 21 | G2 (Gate) | 21 | D2 (Gate) | 21 | D#1 (keyb) | 21 | D#2 (keyb) | 21 | D#3 (keyb) | 21
20 | G3 (Gate) | 20 | D3 (Gate) | 20 | D1 (keyb) | 20 | D2 (keyb) | 20 | D3 (keyb) | 20 | D4 (keyb) | 20 | Res Out 2 | 20 | | 20 | G3 (Gate) | 20 | D3 (Gate) | 20 | D1 (keyb) | 20 | D2 (keyb) | 20 | D3 (keyb) | 20
19 | G4 (Gate) | 19 | D4 (Gate) | 19 | C#1 (keyb) | 19 | C#2 (keyb) | 19 | C#3 (keyb) | 19 | C#4 (keyb) | 19 | GND2 | 19 | P50% Select | 19 | G4 (Gate) | 19 | D4 (Gate) | 19 | C#1 (keyb) | 19 | C#2 (keyb) | 19 | C#3 (keyb) | 19
18 | F#1 (Gate) | 18 | D#1 (Gate) | 18 | C1 (keyb) | 18 | C2 (keyb) | 18 | C3 (keyb) | 18 | C4 (keyb) | 18 | Res Out 1 | 18 | P30% Select | 18 | F#1 (Gate) | 18 | D#1 (Gate) | 18 | C1 (keyb) | 18 | C2 (keyb) | 18 | C3 (keyb) | 18
17 | F#2 (Gate) | 17 | D#2 (Gate) | 17 | B1 (keyb) | 17 | B2 (keyb) | 17 | B3 (keyb) | 17 | B4 (keyb) | 17 | GND2 | 17 | P10% Select | 17 | F#2 (Gate) | 17 | D#2 (Gate) | 17 | B1 (keyb) | 17 | B2 (keyb) | 17 | B3 (keyb) | 17
16 | F#3 (Gate) | 16 | D#3 (Gate) | 16 | A#1 (keyb) | 16 | A#2 (keyb) | 16 | A#3 (keyb) | 16 | A#4 (keyb) | 16 | Res In | 16 | PWM Select | 16 | F#3 (Gate) | 16 | D#3 (Gate) | 16 | A#1 (keyb) | 16 | A#2 (keyb) | 16 | A#3 (keyb) | 16
15 | F#4 (Gate) | 15 | D#4 (Gate) | 15 | A1 (keyb) | 15 | A2 (keyb) | 15 | A3 (keyb) | 15 | A4 (keyb) | 15 | | 15 | PWM In | 15 | F#4 (Gate) | 15 | D#4 (Gate) | 15 | A1 (keyb) | 15 | A2 (keyb) | 15 | A3 (keyb) | 15
14 | F1 (Gate) | 14 | E1 (Gate) | 14 | G#1 (keyb) | 14 | G#2 (keyb) | 14 | G#3 (keyb) | 14 | G#4 (keyb) | 14 | | 14 | Tri Select | 14 | F1 (Gate) | 14 | E1 (Gate) | 14 | G#1 (keyb) | 14 | G#2 (keyb) | 14 | G#3 (keyb) | 14
13 | F2 (Gate) | 13 | E2 (Gate) | 13 | G1 (keyb) | 13 | G2 (keyb) | 13 | G3 (keyb) | 13 | G4 (keyb) | 13 | | 13 | WFD (Sig) | 13 | F2 (Gate) | 13 | E2 (Gate) | 13 | G1 (keyb) | 13 | G2 (keyb) | 13 | G3 (keyb) | 13
12 | F3 (Gate) | 12 | E3 (Gate) | 12 | F#1 (keyb) | 12 | F#2 (keyb) | 12 | F#3 (keyb) | 12 | F#4 (keyb) | 12 | | 12 | WFR (Sig) | 12 | F3 (Gate) | 12 | E3 (Gate) | 12 | F#1 (keyb) | 12 | F#2 (keyb) | 12 | F#3 (keyb) | 12
11 | F4 (Gate) | 11 | E4 (Gate) | 11 | F1 (keyb) | 11 | F2 (keyb) | 11 | F3 (keyb) | 11 | F4 (keyb) | 11 | Peak Cont 3 | 11 | Saw Select | 11 | F4 (Gate) | 11 | E4 (Gate) | 11 | F1 (keyb) | 11 | F2 (keyb) | 11 | F3 (keyb) | 11
10 | | 10 | | 10 | nc / G2 (?) | 10 | nc / G2 (?) | 10 | nc / G2 (?) | 10 | nc / G2 (?) | 10 | Peak Cont 2 | 10 | FC L | 10 | | 10 | | 10 | nc / G2 (?) | 10 | nc / G2 (?) | 10 | nc / G2 (?) | 10
9 | | 9 | | 9 | (?) | 9 | (?) | 9 | (?) | 9 | (?) | 9 | Peak Cont 1 | 9 | FC U | 9 | | 9 | | 9 | (?) | 9 | (?) | 9 | (?) | 9
8 | | 8 | | 8 | Key Trig | 8 | Key Trig | 8 | Key Trig | 8 | Key Trig | 8 | Res Mod 2 | 8 | Balance | 8 | | 8 | | 8 | Key Trig | 8 | Key Trig | 8 | Key Trig | 8
7 | WFR | 7 | WFR | 7 | +10V | 7 | +10V | 7 | +10V | 7 | +10V | 7 | Res Mod 1 | 7 | VCF Mod 2 | 7 | WFR | 7 | WFR | 7 | +10V | 7 | +10V | 7 | +10V | 7
6 | WFD | 6 | WFD | 6 | Release | 6 | Release | 6 | Release | 6 | Release | 6 REL GND On | 6 | VCF Mod 1 | 6 | WFD | 6 | WFD | 6 | Release | 6 | Release | 6 | Release | 6
5 | 5 | 5 | Peak | 5 | Peak | 5 | Peak | 5 | Peak | 5Gate REL Term | 5 | VCF FC | 5 | 5 | 5 | Peak | 5 | Peak | 5 | Peak | 5
4 | | 4 | | 4 | GND3 | 4 | GND3 | 4 | GND3 | 4 | GND3 | 4 | HD GND On | 4 | FC Bias | 4 | | 4 | | 4 | GND3 | 4 | GND3 | 4 | GND3 | 4
3 | -15V | 3 | -15V | 3 | -15V | 3 | -15V | 3 | -15V | 3 | -15V | 3 | -15V | 3 | -15V | 3 | -15V | 3 | -15V | 3 | -15V | 3 | -15V | 3 | -15V | 3
2 | GND | 2 | GND | 2 | GND | 2 | GND | 2 | GND | 2 | GND | 2 | GND | 2 | GND | 2 | GND | 2 | GND | 2 | GND | 2 | GND | 2 | GND | 2
1 | +15V | 1 | +15V | 1 | +15V | 1 | +15V | 1 | +15V | 1 | +15V | 1 | +15V | 1 | +15V | 1 | +15V | 1 | +15V | 1 | +15V | 1 | +15V | 1 | +15V | 1

## Korg PS 3300

## Board Contacts

from front view | PS 3301 - 3 | PS 3302
KLM 69 | | KLM 62 | | KLM 63 | | KLM 64 | | KLM 64 | | KLM 69 | | KLM 69 | | KLM 69 | | KLM 69 | | KLM 62 | | KLM 63 | | KLM 76 | | KLM 77
Gate | | Ctrl 1 | | Ctrl 2 | | Sig | | Sig | | Gate | | Gate | | Gate | | Gate | | Ctrl 1 | | Ctrl 2 | | Ctrl 3 | | Mixer
L Out | 44 | FC Mod R2 | 44 | MG1 FC Ctr | 44 | F (pitch) | 44 | B (pitch) | 44 | L Out | 44 | L Out | 44 | L Out | 44 | L Out | 44 | FC Mod R2 | 44 | MG1 FC Ctr | 44 | | 44
U Out | 43 | FC Mod R1 | 43 | MG1 FC Ctr | 43 | F# (pitch) | 43 | C (pitch) | 43 | U Out | 43 | U Out | 43 | U Out | 43 | U Out | 43 | FC Mod R1 | 43 | MG1 FC Ctr | 43 | | 43
FC U | 42 | FC Mod 2 | 42 | MG1pNoise | 42 | G (pitch) | 42 | C# (pitch) | 42 | FC U | 42 | FC U | 42 | FC U | 42 | FC U | 42 | FC Mod 2 | 42 | MG1pNoise | 42 | 42 Ext Level Ctrl
FC L | 41 | FC Mod 1 | 41 | MG1 wNoise | 41 | G# (pitch) | 41 | D (pitch) | 41 | FC L | 41 | FC L | 41 | FC L | 41 | FC L | 41 | FC Mod 1 | 41 | MG1 wNoise | 41 | | 41 | Phone Out
Decay | 40 | FC Fine | 40 | | 40 | A (pitch) | 40 | D# (pitch) | 40 | Decay | 40 | Decay | 40 | Decay | 40 | Decay | 40 | FC Fine | 40 | | 40 | GND2 | 40 | Phone Level
Ext.Attack | 39 | FC Coarse | 39 | | 39 | A#(pitch) | 39 | E (pitch) | 39 | Ext.Attack | 39 | Ext.Attack | 39 | Ext.Attack | 39 | Ext.Attack | 39 | FC Coarse | 39 | | 39 | | 39
Attack | 38 | GND3 | 38 | GND3 | 38 | 4' | 38 | 4' | 38 | Attack | 38 | Attack | 38 | Attack | 38 | Attack | 38 | GND3 | 38 | GND3 | 38 | | 38
Expand | 37 | FC Bus Out | 37 | MG1 Tri | 37 | 8' | 37 | 8' | 37 | Expand | 37 | Expand | 37 | Expand | 37 | Expand | 37 | FC Bus Out | 37 | MG1 Tri | 37 | | 37 | Mix OUT ?
Sustain | 36 | -15 V | 36 | MG1 Rect | 36 | 16' | 36 | 16' | 36 | Sustain | 36 | Sustain | 36 | Sustain | 36 | Sustain | 36 | -15 V | 36 | MG1 Rect | 36 | | 36
Hold | 35 | GND2 | 35 | MG1 Saw dn | 35 | 35 | 35 | Hold | 35 | Hold | 35 | Hold | 35 | Hold | 35 | GND2 | 35 | MG1 Saw dn | 35 | 35 Mix Ch 3 In ?
E4 (sig) | 34 | L-Out (Mix) | 34 | MG1 Saw up | 34 | A#1 (Gate) | 34 | B1 (Gate) | 34 | E1 (sig) | 34 | E2 (sig) | 34 | E3 (sig) | 34 | E4 (sig) | 34 | L-Out (Mix) | 34 | MG1 Saw up | 34 | | 34
D#4 (sig) | 33 | GND2 | 33 | MG 1 ind | 33 | A#2 (Gate) | 33 | B2 (Gate) | 33 | D#1 (sig) | 33 | D#2 (sig) | 33 | D#3 (sig) | 33 | D#4 (sig) | 33 | GND2 | 33 | MG 1 ind | 33 | 33 Mix CH 2 In ?
D4 (sig) | 32 | L-In (Mix) | 32 | Ind 1 in | 32 | A#3 (Gate) | 32 | B3 (Gate) | 32 | D1 (sig) | 32 | D2 (sig) | 32 | D3 (sig) | 32 | D4 (sig) | 32 | L-In (Mix) | 32 | Ind 1 in | 32 | | 32
C#4 (sig) | 31 | GND2 | 31 | MG2 Sig Out | 31 | A#4 (Gate) | 31 | B4 (Gate) | 31 | C#1 (sig) | 31 | C#2 (sig) | 31 | C#3 (sig) | 31 | C#4 (sig) | 31 | GND2 | 31 | MG2 Sig Out | 31 | 31 Mix CH 1 In ?
C4 (sig) | 30 | U-Out (Mix) | 30 | MG2 Sig In | 30 | A1 (Gate) | 30 | C1 (Gate) | 30 | C1 (sig) | 30 | C2 (sig) | 30 | C3 (sig) | 30 | C4 (sig) | 30 | U-Out (Mix) | 30 | MG2 Sig In | 30 | | 30
B4 (sig) | 29 | GND2 | 29 | MG VCA Ctr. | 29 | A2 (Gate) | 29 | C2 (Gate) | 29 | B1 (sig) | 29 | B2 (sig) | 29 | B3 (sig) | 29 | B4 (sig) | 29 | GND2 | 29 | MG VCA Ctr. | 29 | | 29
A#4 (sig) | 28 | U-In (Mix) | 28 | MG2 Ind | 28 | A3 (Gate) | 28 | C3 (Gate) | 28 | A#1 (sig) | 28 | A#2 (sig) | 28 | A#3 (sig) | 28 | A#4 (sig) | 28 | U-In (Mix) | 28 | MG2 Ind | 28 | LMB 2 | 28 | CH 3 Ctrl
A4 (sig) | 27 | GND2 | 27 | MG2 Out | 27 | A4 (Gate) | 27 | C4 (Gate) | 27 | A1 (sig) | 27 | A2 (sig) | 27 | A3 (sig) | 27 | A4 (sig) | 27 | GND2 | 27 | MG2 Out | 27 | LMA 2 | 27 | CH 3 Switch
G#4 (sig) | 26 | AM Sig Out | 26 | MG Freq. | 26 | G#1 (Gate) | 26 | C#1 (Gate) | 26 | G#1 (sig) | 26 | G#2 (sig) | 26 | G#3 (sig) | 26 | G#4 (sig) | 26 | AM Sig Out | 26 | MG Freq. | 26 | Proc 2 out | 26 | GND
G4 (sig) | 25 | GND2 | 25 | | 25 | G#2 (Gate) | 25 | C#2 (Gate) | 25 | G1 (sig) | 25 | G2 (sig) | 25 | G3 (sig) | 25 | G4 (sig) | 25 | GND2 | 25 | | 25 | Proc 1 Out | 25 | CH 3 Out
F#4 (sig) | 24 | AM Sig in | 24 | | 24 | G#3 (Gate) | 24 | C#3 (Gate) | 24 | F#1 (sig) | 24 | F#2 (sig) | 24 | F#3 (sig) | 24 | F#4 (sig) | 24 | AM Sig in | 24 | | 24 | LMB 1 | 24 | GND
F4 (sig) | 23 | AM Mod In | 23 | | 23 | G#4 (Gate) | 23 | C#4 (Gate) | 23 | F1 (sig) | 23 | F2 (sig) | 23 | F3 (sig) | 23 | F4 (sig) | 23 | AM Mod In | 23 | | 23 | LMA 1 | 23 | CH 3 Vol
E4 (keyb) | 22 | GND2 | 22 | GND2 | 22 | G1 (Gate) | 22 | D1 (Gate) | 22 | E1 (keyb) | 22 | E2 (keyb) | 22 | E3 (keyb) | 22 | E4 (keyb) | 22 | GND2 | 22 | GND2 | 22 | LM 1 | 22 | CH 2 Ctrl
D#4 (keyb) | 21 | GND2 | 21 | | 21 | G2 (Gate) | 21 | D2 (Gate) | 21 | D#1 (keyb) | 21 | D#2 (keyb) | 21 | D#3 (keyb) | 21 | D#4 (keyb) | 21 | GND2 | 21 | | 21 | LM 2 | 21 | CH 2 Switch
D4 (keyb) | 20 | Res Out 2 | 20 | | 20 | G3 (Gate) | 20 | D3 (Gate) | 20 | D1 (keyb) | 20 | D2 (keyb) | 20 | D3 (keyb) | 20 | D4 (keyb) | 20 | Res Out 2 | 20 | | 20 | VP 2 In | 20 | GND
C#4 (keyb) | 19 | GND2 | 19 | P50% Select | 19 | G4 (Gate) | 19 | D4 (Gate) | 19 | C#1 (keyb) | 19 | C#2 (keyb) | 19 | C#3 (keyb) | 19 | C#4 (keyb) | 19 | GND2 | 19 | P50% Select | 19 | VP 1 In | 19 | CH 2 Out
C4 (keyb) | 18 | Res Out 1 | 18 | P30% Select | 18 | F#1 (Gate) | 18 | D#1 (Gate) | 18 | C1 (keyb) | 18 | C2 (keyb) | 18 | C3 (keyb) | 18 | C4 (keyb) | 18 | Res Out 1 | 18 | P30% Select | 18 | GEG Attack | 18 | GND
B4 (keyb) | 17 | GND2 | 17 | P10% Select | 17 | F#2 (Gate) | 17 | D#2 (Gate) | 17 | B1 (keyb) | 17 | B2 (keyb) | 17 | B3 (keyb) | 17 | B4 (keyb) | 17 | GND2 | 17 | P10% Select | 17 | GEG Out 0V | 17 | CH 2 Vol
A#4 (keyb) | 16 | Res In | 16 | PWM Select | 16 | F#3 (Gate) | 16 | D#3 (Gate) | 16 | A#1 (keyb) | 16 | A#2 (keyb) | 16 | A#3 (keyb) | 16 | A#4 (keyb) | 16 | Res In | 16 | PWM Select | 16 GEG Out +5V | 16
A4 (keyb) | 15 | 15 | PWM In | 15 | F#4 (Gate) | 15 | D#4 (Gate) | 15 | A1 (keyb) | 15 | A2 (keyb) | 15 | A3 (keyb) | 15 | A4 (keyb) | 15 | 15 | PWM In | 15GEG Auto Ou | 15
G#4 (keyb) | 14 | 14 | Tri Select | 14 | F1 (Gate) | 14 | E1 (Gate) | 14 | G#1 (keyb) | 14 | G#2 (keyb) | 14 | G#3 (keyb) | 14 | G#4 (keyb) | 14 | 14 | Tri Select | 14 GEG Out -5V | 14 | CH 1 Ctrl
G4 (keyb) | 13 | 13 | WFD (Sig) | 13 | F2 (Gate) | 13 | E2 (Gate) | 13 | G1 (keyb) | 13 | G2 (keyb) | 13 | G3 (keyb) | 13 | G4 (keyb) | 13 | 13 | WFD (Sig) | 13 GEG Release | 13 | CH 1 Switch
F#4 (keyb) | 12 | | 12 | WFR (Sig) | 12 | F3 (Gate) | 12 | E3 (Gate) | 12 | F#1 (keyb) | 12 | F#2 (keyb) | 12 | F#3 (keyb) | 12 | F#4 (keyb) | 12 | | 12 | WFR (Sig) | 12 | GEG Auto In | 12 | GND
F4 (keyb) | 11 | Peak Cont 3 | 11 | Saw Select | 11 | F4 (Gate) | 11 | E4 (Gate) | 11 | F1 (keyb) | 11 | F2 (keyb) | 11 | F3 (keyb) | 11 | F4 (keyb) | 11 | Peak Cont 3 | 11 | Saw Select | 11 | GEG Trig In | 11 | CH 1 Out
nc / G2 (?) | 10 | Peak Cont 2 | 10 | FC L | 10 | | 10 | | 10 | nc / G2 (?) | 10 | nc / G2 (?) | 10 | nc / G2 (?) | 10 | nc / G2 (?) | 10 | Peak Cont 2 | 10 | FC L | 10 | GEG Delay | 10 | GND
(?) | 9 | Peak Cont 1 | 9 | FC U | 9 | | 9 | | 9 | (?) | 9 | (?) | 9 | (?) | 9 | (?) | 9 | Peak Cont 1 | 9 | FC U | 9 | Sync Ind | 9 | CH 1 Vol
Key Trig | 8 | Res Mod 2 | 8 | Balance | 8 | | 8 | | 8 | Key Trig | 8 | Key Trig | 8 | Key Trig | 8 | Key Trig | 8 | Res Mod 2 | 8 | Balance | 8 | Sync In | 8
+10V | 7 | Res Mod 1 | 7 | VCF Mod 2 | 7 | WFR | 7 | WFR | 7 | +10V | 7 | +10V | 7 | +10V | 7 | +10V | 7 | Res Mod 1 | 7 | VCF Mod 2 | 7 | S/H FC In | 7
Release | 6 REL GND On | 6 | VCF Mod 1 | 6 | WFD | 6 | WFD | 6 | Release | 6 | Release | 6 | Release | 6 | Release | 6 REL GND On | 6 | VCF Mod 1 | 6 | S/H In | 6 | Ext Level (?)
Peak | 5Gate REL Term | 5 | VCF FC | 5 | 5 | 5 | Peak | 5 | Peak | 5 | Peak | 5 | Peak | 5Gate REL Term | 5 | VCF FC | 5 | S/H Out | 5
GND3 | 4 | HD GND On | 4 | FC Bias | 4 | | 4 | | 4 | GND3 | 4 | GND3 | 4 | GND3 | 4 | GND3 | 4 | HD GND On | 4 | FC Bias | 4 | Sync Out | 4
-15V | 3 | -15V | 3 | -15V | 3 | -15V | 3 | -15V | 3 | -15V | 3 | -15V | 3 | -15V | 3 | -15V | 3 | -15V | 3 | -15V | 3 | -15V | 3 | -15V
GND | 2 | GND | 2 | GND | 2 | GND | 2 | GND | 2 | GND | 2 | GND | 2 | GND | 2 | GND | 2 | GND | 2 | GND | 2 | GND | 2 | GND
+15V | 1 | +15V | 1 | +15V | 1 | +15V | 1 | +15V | 1 | +15V | 1 | +15V | 1 | +15V | 1 | +15V | 1 | +15V | 1 | +15V | 1 | +15V | 1 | +15V

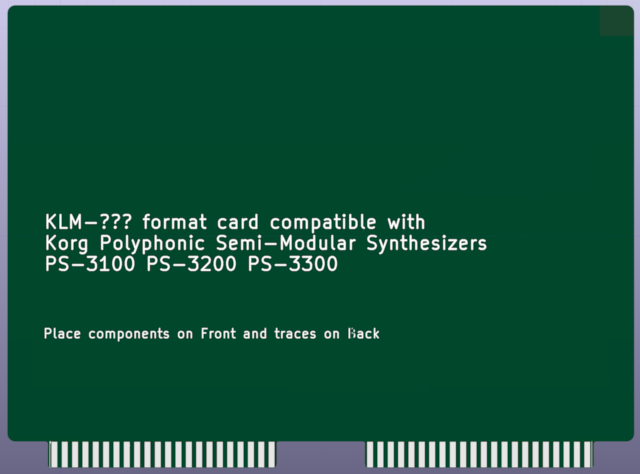
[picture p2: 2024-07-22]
klib/templates/Korg PS-3x00 KLM Cards/meta/preview.png

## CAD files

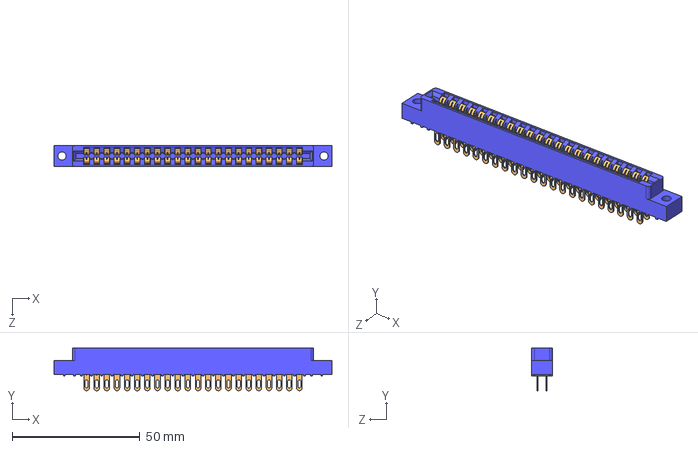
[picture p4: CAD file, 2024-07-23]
klib/footprints/_ _M22DREH.STEP
108.7 x 16.7 x 8.26 mm
10016, M_ _D__M22D
11169, _ _ M - V40__ _ M-V40 ASSY x 44

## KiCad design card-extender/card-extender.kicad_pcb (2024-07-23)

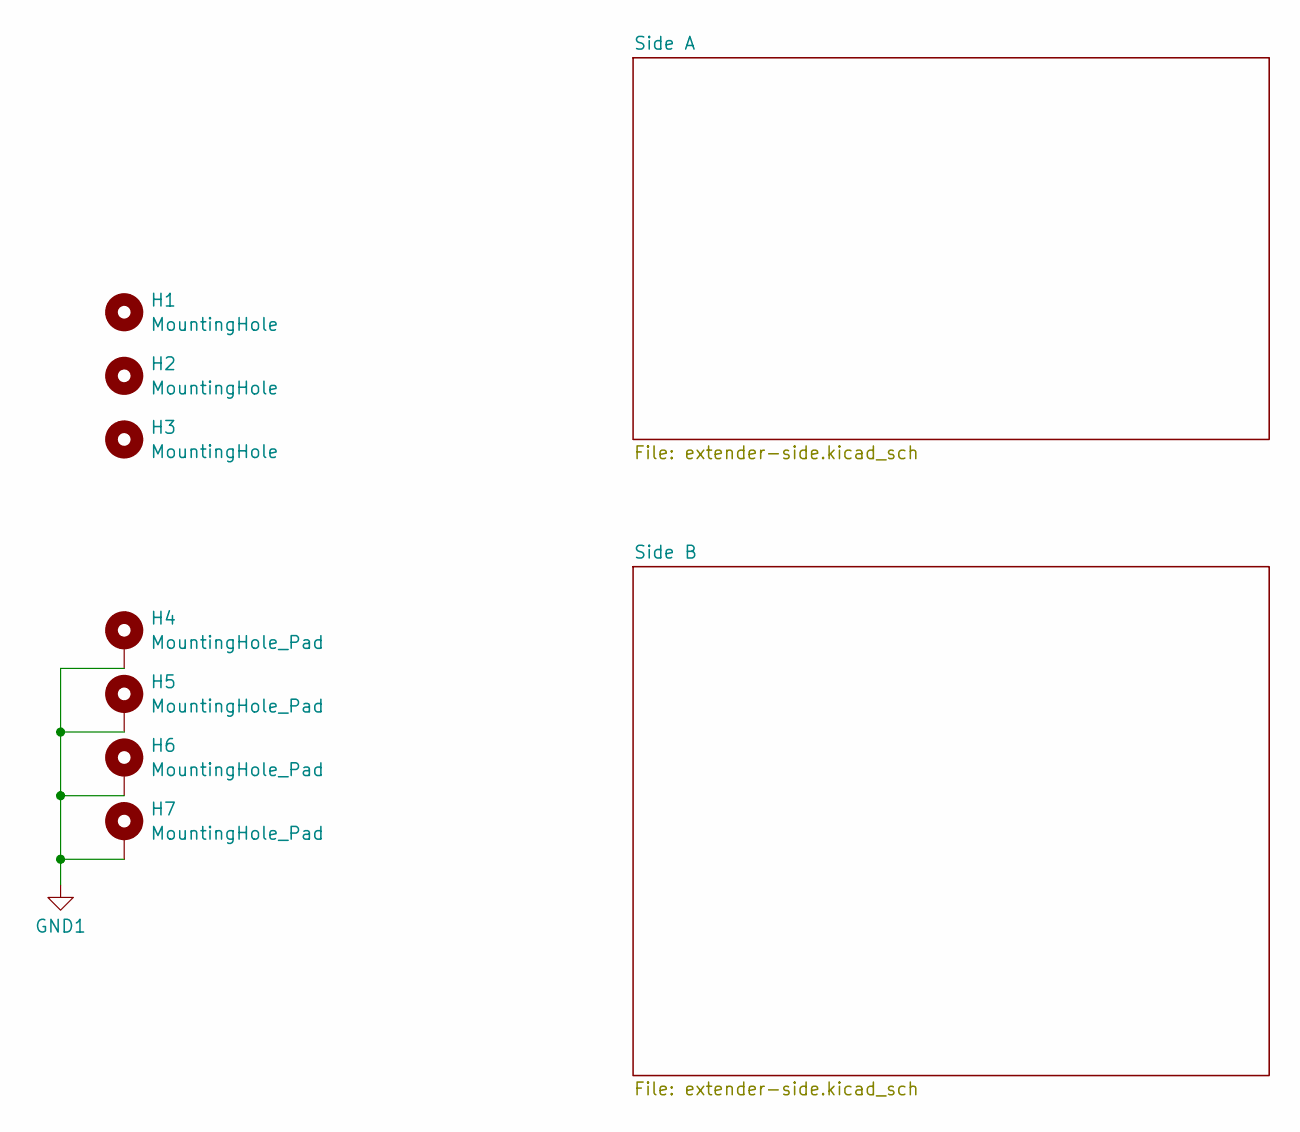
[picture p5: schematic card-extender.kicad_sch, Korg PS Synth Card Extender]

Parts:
H1, H2, H3: MountingHole; MountingHole_2.5mm
H4, H5, H6, H7: MountingHole_Pad; MountingHole_2.2mm_M2_Pad

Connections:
GND1: H4.1, H5.1, H6.1, H7.1

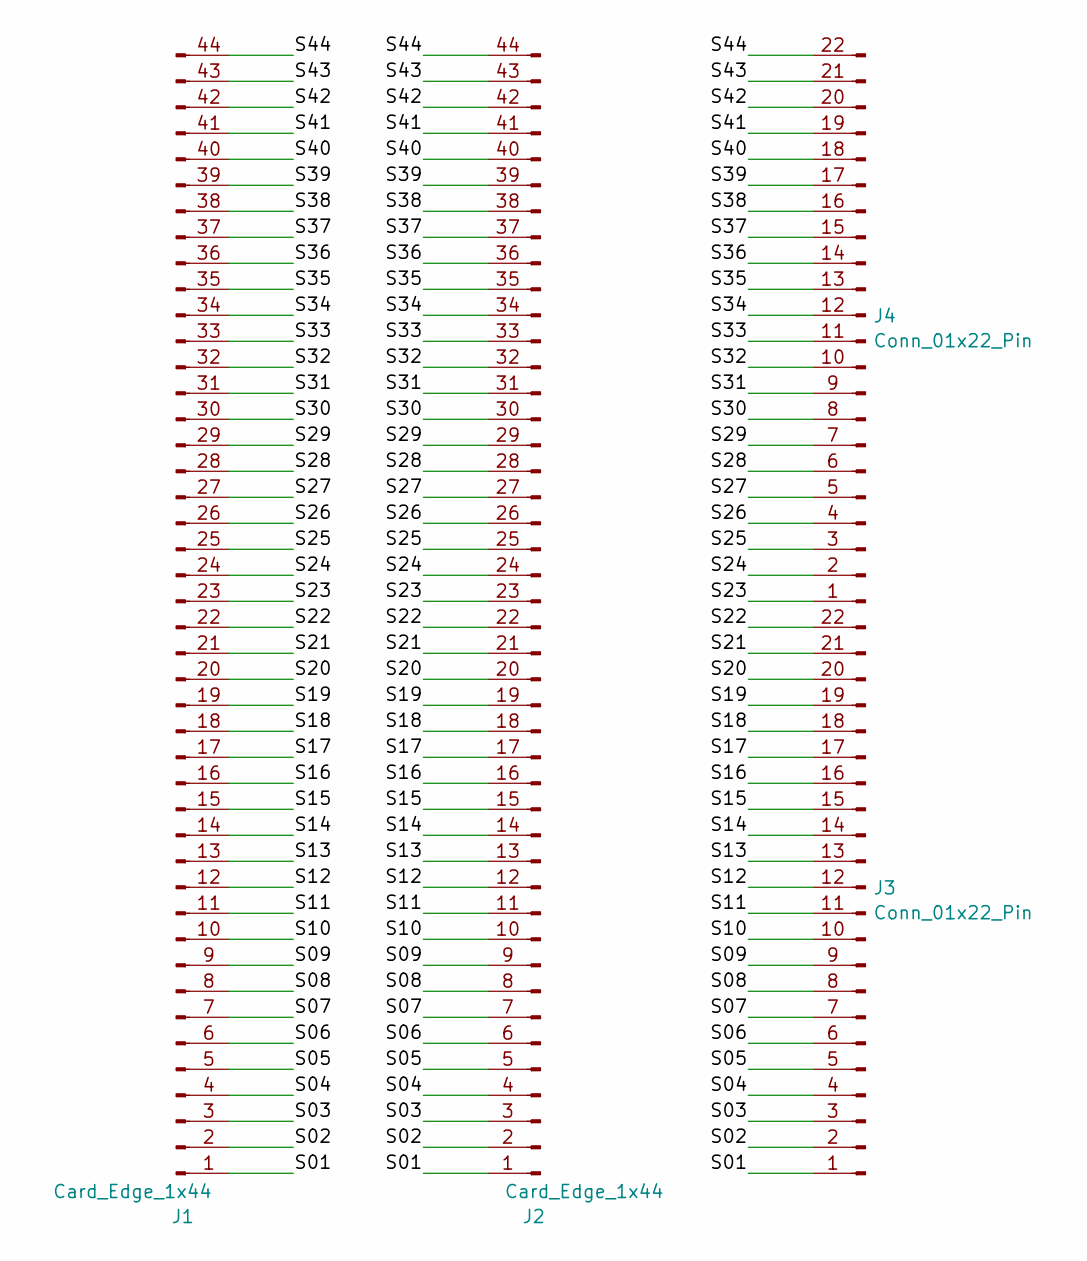
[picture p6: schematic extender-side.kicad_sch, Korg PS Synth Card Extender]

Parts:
J1, J2: Card_Edge_1x44; CardEdge-2x22_2.18x9.75mm_P3.96mm
J3, J4: Conn_01x22_Pin; Molex_KK-396_A-41791-0022_1x22_P3.96mm_Vertical

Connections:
/Side A/S01: J1.1, J2.1, J3.1
/Side A/S02: J1.2, J2.2, J3.2
/Side A/S03: J1.3, J2.3, J3.3
/Side A/S04: J1.4, J2.4, J3.4
/Side A/S05: J1.5, J2.5, J3.5
/Side A/S06: J1.6, J2.6, J3.6
/Side A/S07: J1.7, J2.7, J3.7
/Side A/S08: J1.8, J2.8, J3.8
/Side A/S09: J1.9, J2.9, J3.9
/Side A/S10: J1.10, J2.10, J3.10
/Side A/S11: J1.11, J2.11, J3.11
/Side A/S12: J1.12, J2.12, J3.12
/Side A/S13: J1.13, J2.13, J3.13
/Side A/S14: J1.14, J2.14, J3.14
/Side A/S15: J1.15, J2.15, J3.15
/Side A/S16: J1.16, J2.16, J3.16
/Side A/S17: J1.17, J2.17, J3.17
/Side A/S18: J1.18, J2.18, J3.18
/Side A/S19: J1.19, J2.19, J3.19
/Side A/S20: J1.20, J2.20, J3.20
/Side A/S21: J1.21, J2.21, J3.21
/Side A/S22: J1.22, J2.22, J3.22
/Side A/S23: J1.23, J2.23, J4.1
/Side A/S24: J1.24, J2.24, J4.2
/Side A/S25: J1.25, J2.25, J4.3
/Side A/S26: J1.26, J2.26, J4.4
/Side A/S27: J1.27, J2.27, J4.5
/Side A/S28: J1.28, J2.28, J4.6
/Side A/S29: J1.29, J2.29, J4.7
/Side A/S30: J1.30, J2.30, J4.8
/Side A/S31: J1.31, J2.31, J4.9
/Side A/S32: J1.32, J2.32, J4.10
/Side A/S33: J1.33, J2.33, J4.11
/Side A/S34: J1.34, J2.34, J4.12
/Side A/S35: J1.35, J2.35, J4.13
/Side A/S36: J1.36, J2.36, J4.14
/Side A/S37: J1.37, J2.37, J4.15
/Side A/S38: J1.38, J2.38, J4.16
/Side A/S39: J1.39, J2.39, J4.17
/Side A/S40: J1.40, J2.40, J4.18
/Side A/S41: J1.41, J2.41, J4.19
/Side A/S42: J1.42, J2.42, J4.20
/Side A/S43: J1.43, J2.43, J4.21
/Side A/S44: J1.44, J2.44, J4.22

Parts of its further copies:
J5, J6: Card_Edge_1x44; CardEdge-2x22_2.18x9.75mm_P3.96mm
J7, J8: Conn_01x22_Pin; Molex_KK-396_A-41791-0022_1x22_P3.96mm_Vertical

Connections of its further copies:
/Side B/S01: J5.1, J6.1, J7.1
/Side B/S02: J5.2, J6.2, J7.2
/Side B/S03: J5.3, J6.3, J7.3
/Side B/S04: J5.4, J6.4, J7.4
/Side B/S05: J5.5, J6.5, J7.5
/Side B/S06: J5.6, J6.6, J7.6
/Side B/S07: J5.7, J6.7, J7.7
/Side B/S08: J5.8, J6.8, J7.8
/Side B/S09: J5.9, J6.9, J7.9
/Side B/S10: J5.10, J6.10, J7.10
/Side B/S11: J5.11, J6.11, J7.11
/Side B/S12: J5.12, J6.12, J7.12
/Side B/S13: J5.13, J6.13, J7.13
/Side B/S14: J5.14, J6.14, J7.14
/Side B/S15: J5.15, J6.15, J7.15
/Side B/S16: J5.16, J6.16, J7.16
/Side B/S17: J5.17, J6.17, J7.17
/Side B/S18: J5.18, J6.18, J7.18
/Side B/S19: J5.19, J6.19, J7.19
/Side B/S20: J5.20, J6.20, J7.20
/Side B/S21: J5.21, J6.21, J7.21
/Side B/S22: J5.22, J6.22, J7.22
/Side B/S23: J5.23, J6.23, J8.1
/Side B/S24: J5.24, J6.24, J8.2
/Side B/S25: J5.25, J6.25, J8.3
/Side B/S26: J5.26, J6.26, J8.4
/Side B/S27: J5.27, J6.27, J8.5
/Side B/S28: J5.28, J6.28, J8.6
/Side B/S29: J5.29, J6.29, J8.7
/Side B/S30: J5.30, J6.30, J8.8
/Side B/S31: J5.31, J6.31, J8.9
/Side B/S32: J5.32, J6.32, J8.10
/Side B/S33: J5.33, J6.33, J8.11
/Side B/S34: J5.34, J6.34, J8.12
/Side B/S35: J5.35, J6.35, J8.13
/Side B/S36: J5.36, J6.36, J8.14
/Side B/S37: J5.37, J6.37, J8.15
/Side B/S38: J5.38, J6.38, J8.16
/Side B/S39: J5.39, J6.39, J8.17
/Side B/S40: J5.40, J6.40, J8.18
/Side B/S41: J5.41, J6.41, J8.19
/Side B/S42: J5.42, J6.42, J8.20
/Side B/S43: J5.43, J6.43, J8.21
/Side B/S44: J5.44, J6.44, J8.22

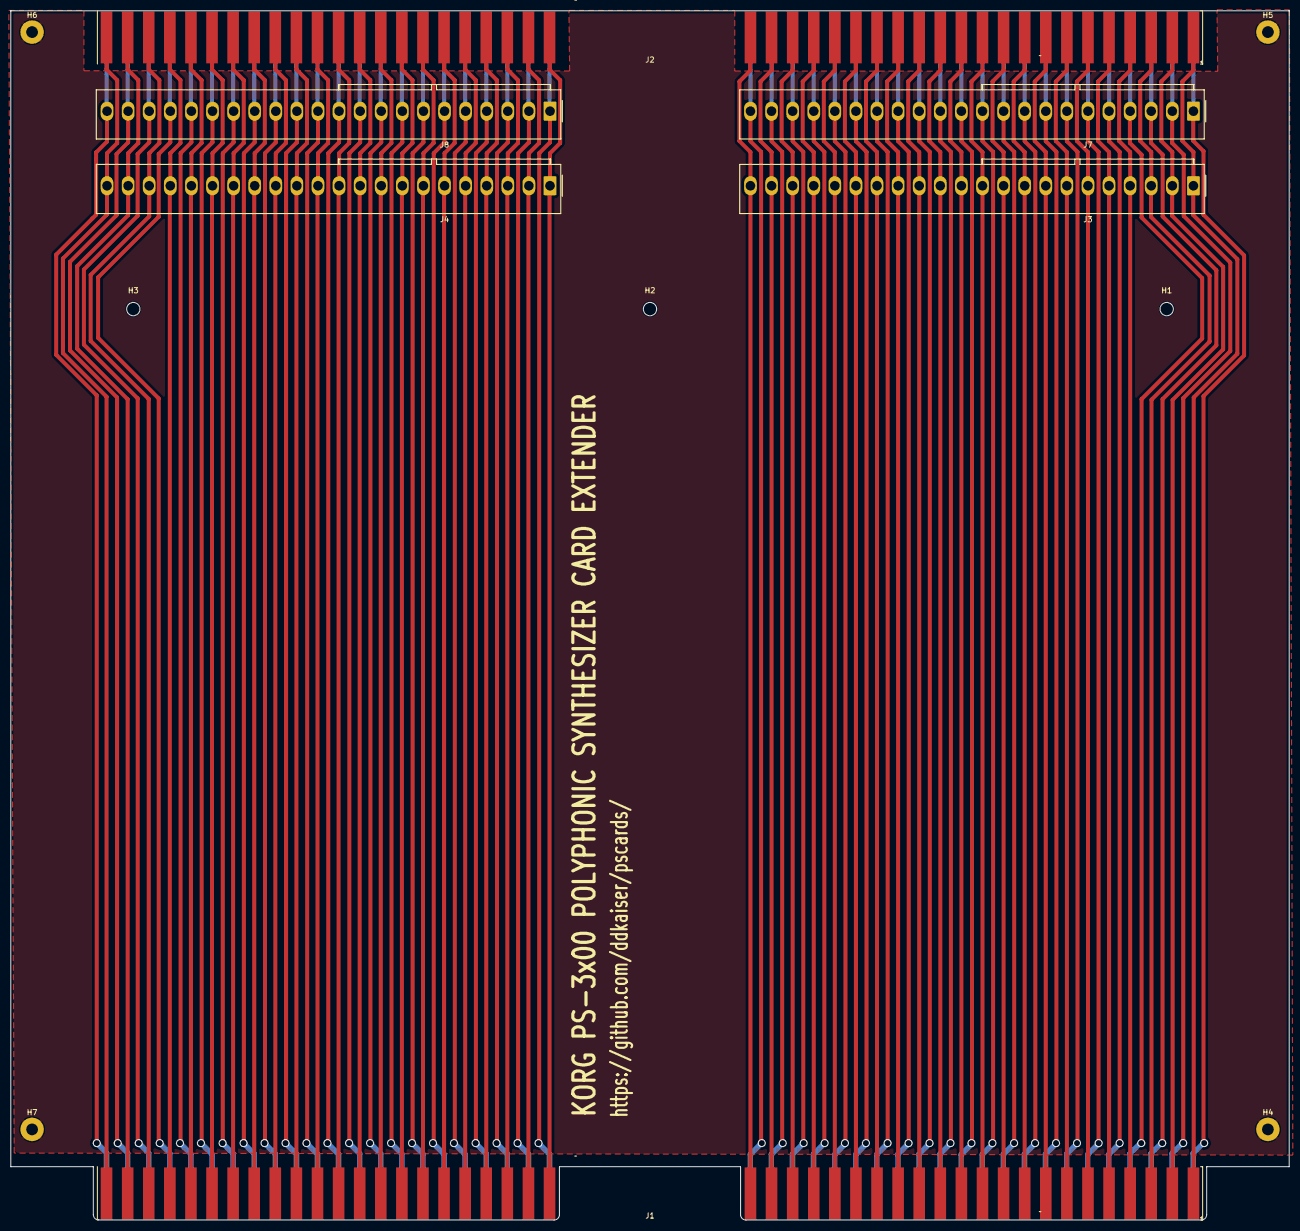
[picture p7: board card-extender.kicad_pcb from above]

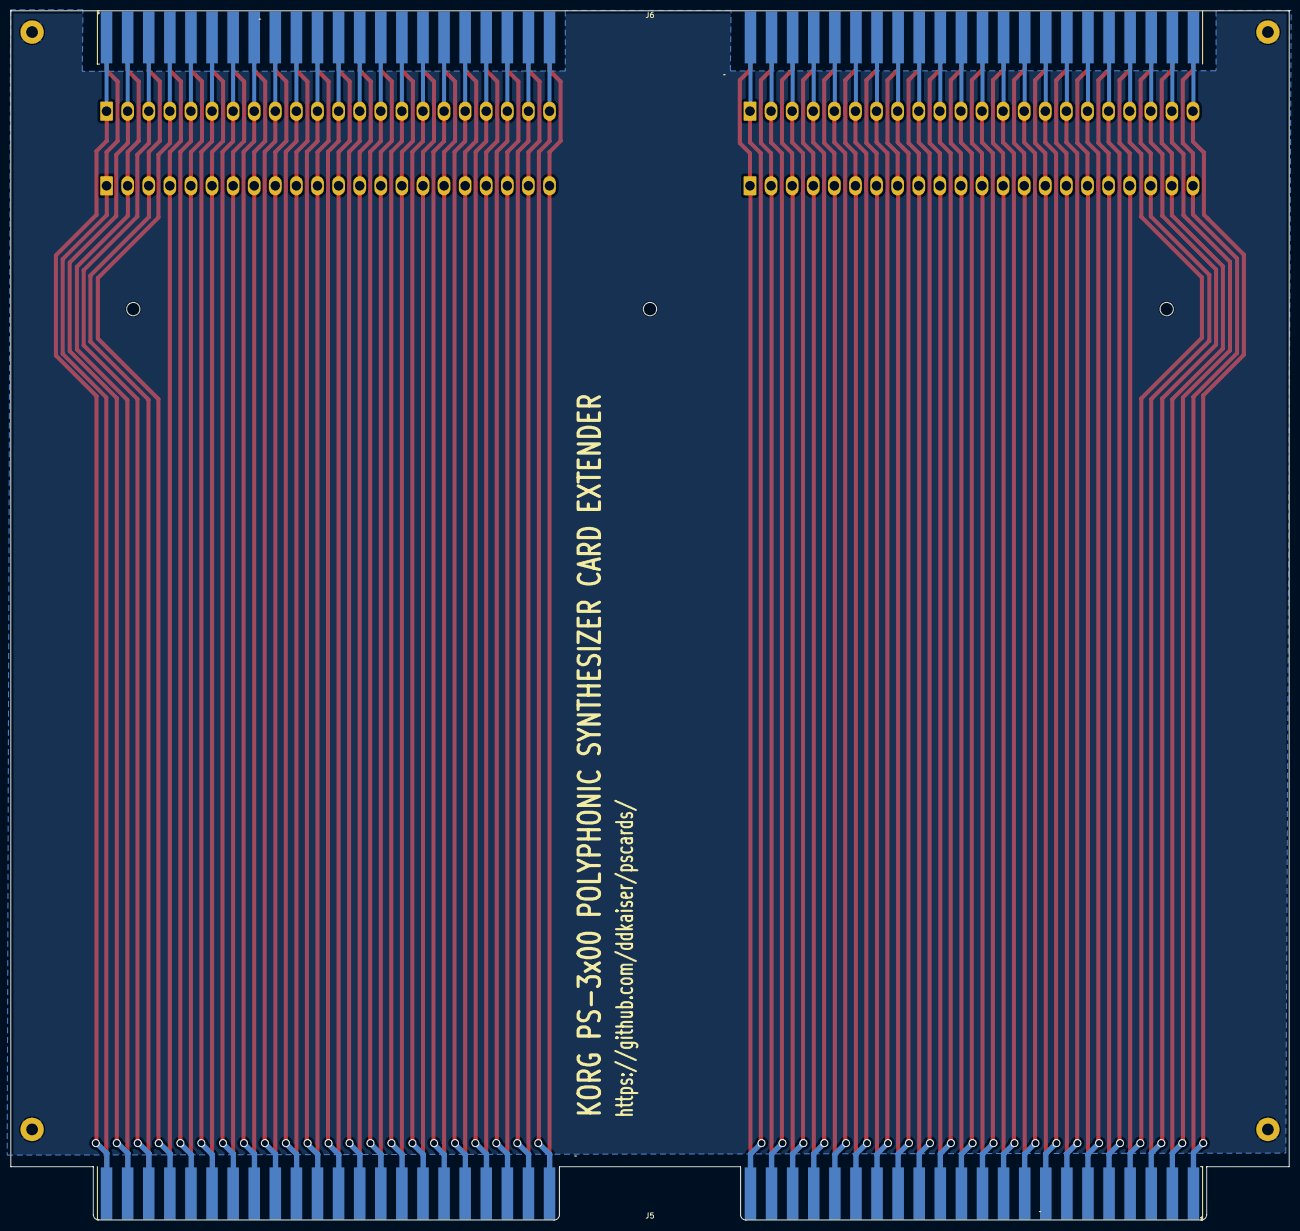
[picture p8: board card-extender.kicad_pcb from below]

Board: 2 copper layers, 240.0 x 227.0 mm, 15 parts (2 on the bottom side), 89 nets.

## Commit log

2024-07-22 added card-extender
    [card-extender.kicad_pcb, card-extender.kicad_sch, extender-side.kicad_sch]
2024-07-22 Starter, template project with empty card
    [Korg PS-3x00 KLM Cards.kicad_pcb, Korg PS-3x00 KLM Cards.kicad_sch]
2024-07-23 moving footprint to project library
2024-07-23 adding 3d model for socket connector
    [_ _M22DREH.STEP, card-extender.kicad_pcb]
2024-07-23 adding attribution fields
    [card-extender.kicad_pcb, card-extender.kicad_sch, extender-side.kicad_sch]
